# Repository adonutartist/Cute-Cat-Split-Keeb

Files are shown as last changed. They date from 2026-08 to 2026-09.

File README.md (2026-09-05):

# nemoPAD V1

A wireless split mechanical keyboard with per key kalih hotswap sockets, per key underglow RGB, a slide potentiometer for brightness control on the right half, and a rotary encoder for volume control on the left half. Uses a sandwich mount case (bottom case + plate + top frame) held together with heatset inserts and m2 20mm screws. The CAD features a unique design so it can join up to change into a full keeb visually. A project by Nemo made for Forge YSWS by Hackclub.

NOTE TO REVIEWER: I didn't make an assembly with case PCB and all components because Importing PCB into onshape was way too laggy and crashed, Adding lots of components also made onshape lag like crazy and crash so I abandoned doing that I hope you understand. I have a potato laptop from 2020 its really a budget laptop so please understand... 

## Useful links
- **Total time spent:** [56h 2m](https://hackatime.hackclub.com/@Nemo_Donut/project/Keeb)
- **Devlogs:** [`JOURNAL.md`](./JOURNAL.md)
- **Onshape:** [CAD part of the project](https://cad.onshape.com/documents/d864244cbdf9531af3bfa9a7/w/1dab6020ee26630806b280f9/e/8f26d1999df9f3097243071e)

## Features
- Wireless split halves, each with its own XIAO nRF52840 MCU and LiPo battery
- Full hotswap (Kailh CPG151101S11 sockets), no soldering required for switches
- Per key RGB backlight using reverse mount underglow (SK6812MINI-E)
- MCP23017 I2C GPIO expander per half for full matrix coverage
- Slide potentiometer (right half) for brightness
- Rotary encoder with push (left half) for volume
- Sandwich mount case: top frame + plate + bottom case, screwed together with heatset inserts and m2 20mm screws

## Images
- Full 3D model render of the assembled keyboard (both halves)
  

- PCB render/photo with components populated (both halves)
  

- Schematic screenshots (1st image is left and 2nd image is right)
  

- Exploded view of the sandwich mount stack (bottom case / plate / top frame)
  

- Decal logo, custom encoder knob and hackclub logo emboss
  

## From concept to CAD
<p align="center">
  1dd2464e-4f92-4cd7-a45b-adbc3583a7b4
  &nbsp;&nbsp;&nbsp;&nbsp;➡️&nbsp;&nbsp;&nbsp;&nbsp;
  
</p>

## Hardware design

### Sandwich mount stackup
| Layer | Thickness | Notes |
|---|---|---|
| Top frame | 6.3mm | Blind hole Ø3.5mm, 4.6mm deep for the heatset insert, no hole visible from outside |
| Plate | 1.5mm | Through hole Ø2.4mm for screw clearance |
| PCB | 1.6mm | |
| Bottom case (inner wall height) | 8mm | Clears the 3.05mm tall hotswap socket + ~3.16mm USB-C connector on the back layer with margin |
| Bottom case (bottom wall) | 3mm | Ø2.4mm x 1.2mm countersink on the underside so the screw head sits flush |

**Case is attached using** M2 x 4mm x 3.8mm OD brass heatset insert, M2 x 20mm countersunk screw.

**Battery pocket:** a local recessed pocket under the battery footprint on the inside of the bottom wall of bottom case (battery is the tallest bottom side component at ~5mm, taller than the general 6mm clearance zone needs). Battery wires are direct soldered to the BAT/GND test points, no connector.

## Bill of Materials
See [`BOM.csv`](./BOM.csv) for the full parts list with references, footprints, product links, and important notes.

### Summarised version:

| Component | Quantity | Total Price |
|---|---|---|
| 1N914 Diodes | 68 | ₹ 159.80 / $1.69 |
| SK6812MINI-E LEDs | 70 | ₹ 619.20 / $6.56 |
| 8.2k Resistor | 2 | ₹ 10.26 / $0.11 |
| 10k Resistor | 2 | ₹ 10.08 / $0.11 |
| Bourns Slide Potentiometer | 1 | ₹ 286.78 / $3.04 |
| Alps EC11E Rotary Encoder | 1 | NA (reused from kit) |
| Kailh Hotswap Sockets (all sizes) | 68 | ₹ 350.00 / $3.71 |
| MX-style Switches (all sizes) | 68 | ₹ 2,598.00 / $27.51 |
| Keycaps – 1u | 60 | ₹ 1,020.00 / $10.80 |
| Keycaps – 1.75u | 4 | ₹ 180.00 / $1.91 |
| Keycaps – 1.5u | 2 | ₹ 180.00 / $1.91 |
| Keycaps – 1.25u | 2 | NA (3D printed) |
| MCP23017 GPIO Expander | 2 | ₹ 539.00 / $5.71 |
| XIAO nRF52840 (modified) | 2 | ₹ 2,418.00 / $25.60 |
| LiPo Battery 500mAh | 2 | ₹ 476.98 / $5.05 |
| PCB (2-layer panel) | 5 | ₹ 5,003.00 / $52.97 |
| Heatset Insert | 8 | ₹ 108.65 / $1.15 |
| Case Screw | 8 | (included above) |
| 3D Printed Parts (case, plate, frame, knob, keycap) | 7 | ₹ 1,956.06 / $20.71 |
| **GRAND TOTAL** | | **₹ 15,915.81 / $168.51** |

## Assembly
1. Solder components to both PCB halves (or have them assembled), separate the panel at the mousebite tabs
2. Solder battery leads to BAT/GND test points on each half
3. Insert hotswap sockets, install switches
4. Heatset the M2 inserts into each top frame's blind holes
5. Sandwich bottom case -> PCB -> plate -> top frame, secure with M2x18mm screws
6. Flahing steps still needs work.

## Flashing

The keyboard uses two Seeed XIAO nRF52840 boards, one for each half. Separate firmware files are provided for the left and right halves.

### Requirements

* USB-C data cable
* Computer
* The appropriate `.uf2` firmware file

### Flash the Left Half

1. Connect the **left-half XIAO nRF52840** to your computer via USB.
2. Double-click the XIAO's **Reset** button to enter bootloader mode.
3. A USB mass-storage drive should appear.
4. Copy `zmk_left.uf2` onto the bootloader drive (Found inside Firmware folder).
5. The XIAO will automatically reboot after the firmware is copied.

### Flash the Right Half

1. Connect the **right-half XIAO nRF52840** to your computer via USB.
2. Double-click the XIAO's **Reset** button to enter bootloader mode.
3. A USB mass-storage drive should appear.
4. Copy `zmk_right.uf2` onto the bootloader drive (Found inside Firmware folder).
5. The XIAO will automatically reboot after the firmware is copied.

### Firmware Source

The firmware is built using **ZMK** with the Seeed XIAO nRF52840 target.

The provided firmware files are:

```text
Firmware/
├── zmk_left.uf2
└── zmk_right.uf2
```

The firmware currently represents the development stage prototype. Both left and right firmware builds complete successfully; physical flashing and keyboard testing will be performed once the PCBs and components are available.

---

<p align="center">
  nemo
</p>

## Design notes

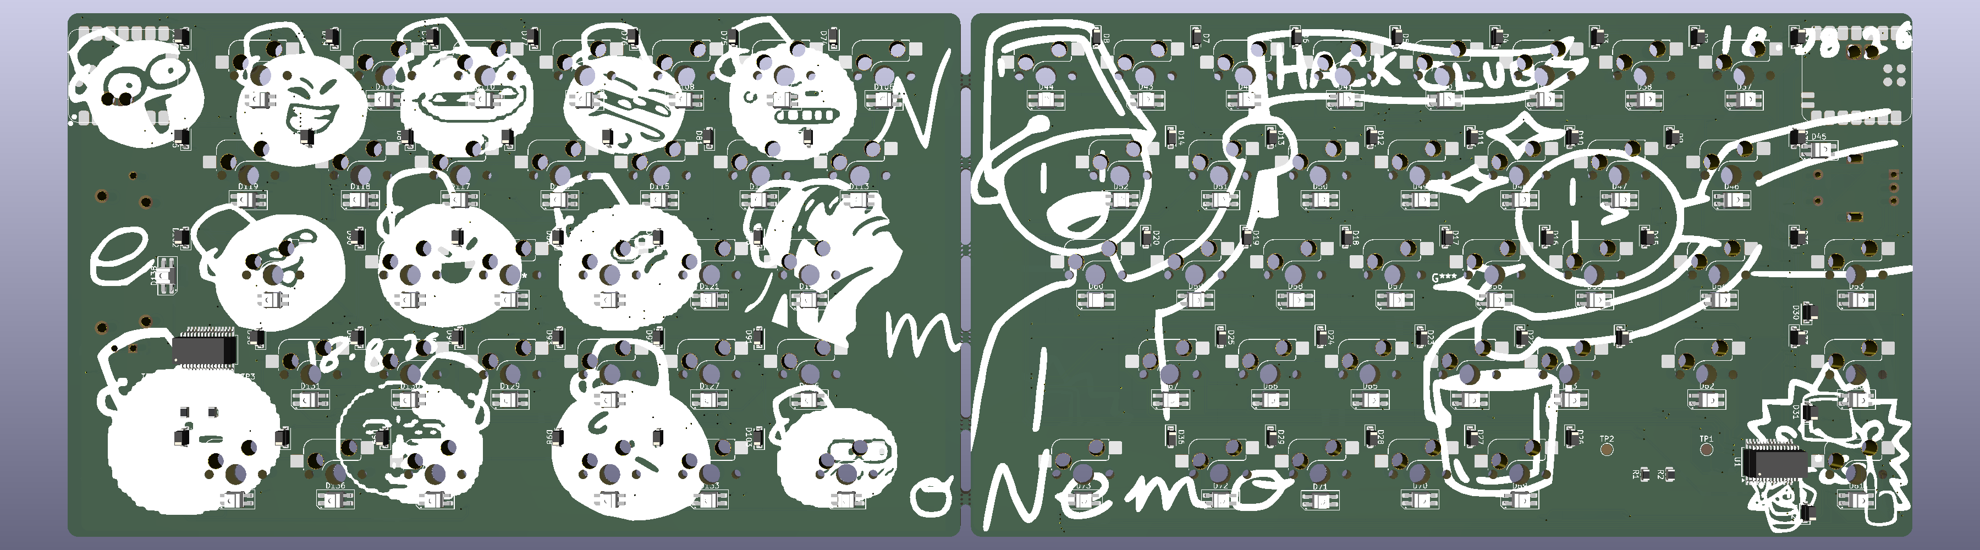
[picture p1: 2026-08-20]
kicad/kicadback.png

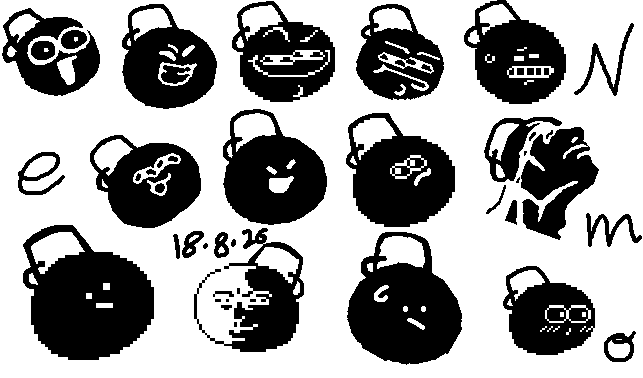
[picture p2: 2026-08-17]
kicad/silkscreen right front.png

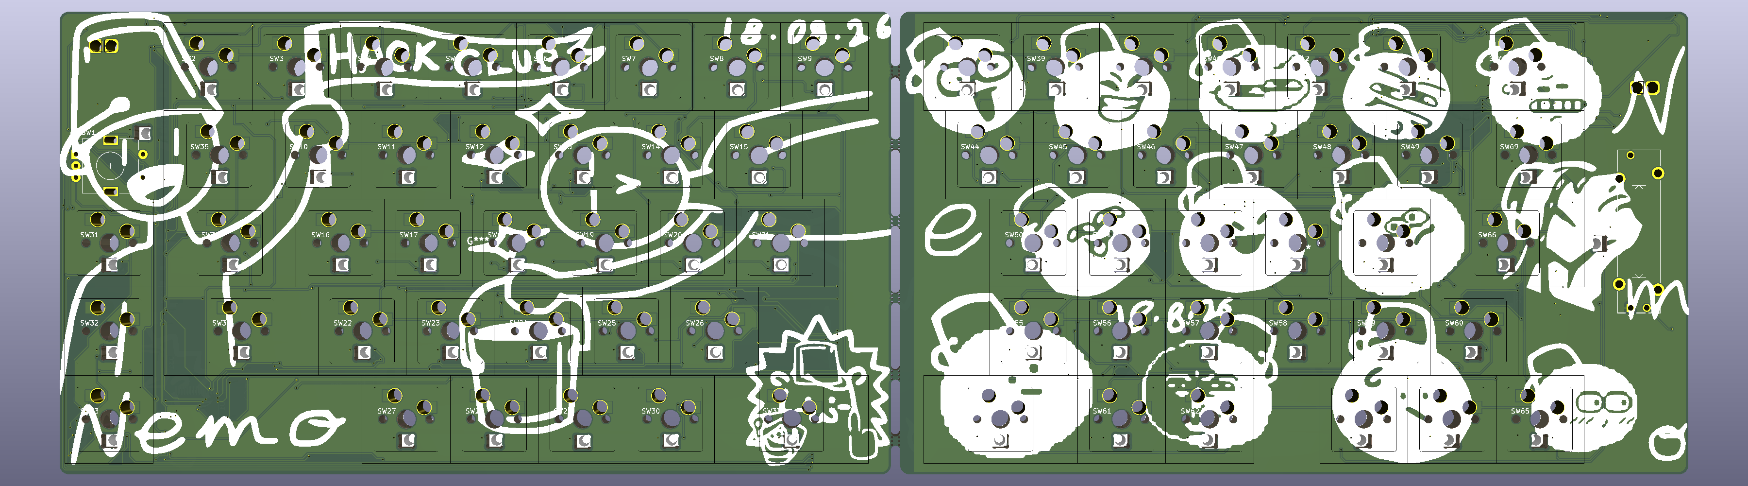
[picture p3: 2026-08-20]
kicad/kicad.png

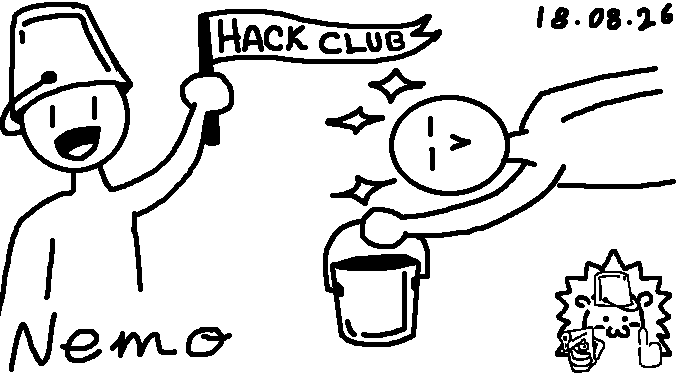
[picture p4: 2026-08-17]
kicad/silkscreen left front.png

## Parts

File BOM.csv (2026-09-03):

Category | Reference(s) | Qty | Part / Value | Footprint / Package | Description | Unit Price | Total | Notes
Electronics | D1-D32 (left), D66-D101 (right) | 68 | 1N914 | SOD-123 | Small signal switching diode (per-key) | ₹ 2.35 / $0.02 | ₹ 159.80 / $1.69 | https://robu.in/product/1n4148w-7-f-diodes-incorporated-100v-independent-type-1-25v150ma-4ns-300ma-sod-123-switching-diodes-rohs/
Electronics | D33-D65 (left), D102-D138 (right) | 70 | SK6812MINI-E | LED_SK6812MINI-E_3.2x2.8mm ReverseMount | Per-key + underglow RGB LED (reverse mount = bottom side) | ₹ 8.60 / $0.09 | ₹ 619.20 / $6.56 | https://www.etstore.in/products/e9974?variant=48993209319675 ; gonna order 72 because it comes in pack of 3
Electronics | R1, R3 | 2 | 8.2k | 8.2k | Battery voltage-divider resistor (top) | ₹ 0.38 / $0.00 | ₹ 10.26 / $0.11 | https://robu.in/product/wr08x8201ftl-walsin-125mw-thick-film-resistors-150v-%c2%b1100ppm-%e2%84%83-%c2%b11-8-2k%cf%89-0805-chip-resistor-surface-mount-rohs/ ; buying 27 to meet minimum order value
Electronics | R2, R4 | 2 | 10k | 10k | Battery voltage-divider resistor (bottom) | ₹ 0.72 / $0.01 | ₹ 10.08 / $0.11 | https://robu.in/product/ac0805fr-0710kl-yageo-res-thick-film-0805-10k-ohm-1-0-125w1-8w-%c2%b1100ppm-c-pad-smd-t-r-automotive-aec-q200/ ; buying 14 to meet minimum order value
Electronics | RV1 | 1 | Bourns PTA2043-2015DPB103 | Potentiometer_Bourns_PTA2043_Single_Slide | Slide potentiometer, 20mm travel, brightness/volume control (left half only) | ₹ 211.78 / $2.24 | ₹ 286.78 / $3.04 | https://www.tanotis.com/products/bourns-pta2043-2015cpb103-pot-slide-10kohm-0-1w?gad_source=1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
Electronics | SW33 | 1 | Alps EC11E | RotaryEncoder_Alps_EC11E-Switch_Vertical_H20mm | Rotary encoder w/ push switch, 20mm vertical shaft (right half only) | NA | NA | got one extra in my hackpad kit so gonna use that
Electronics | SW1-28, SW34-65 | 60 | SW_Push (1u) | PCM_marbastlib-mx CPG151101S11 1u | Kailh hotswap socket - 1u keys | ₹ 5 / $0.05 | ₹ 350 / $3.71 | https://neomacro.in/products/jerrzi-mx-hotswap-sockets?variant=51634860622102 ; i am buying 70 because its a pack of 10
Electronics | SW29-30, SW66, SW69 | 4 | SW_Push (1.75u) | PCM_marbastlib-mx CPG151101S11 1.75u | Kailh hotswap socket - 1.75u keys | same | total above | same
Electronics | SW31, SW68 | 2 | SW_Push (1.5u) | PCM_marbastlib-mx CPG151101S11 1.5u | Kailh hotswap socket - 1.5u keys | same | total above | same
Electronics | SW32, SW67 | 2 | SW_Push (1.25u) | PCM_marbastlib-mx CPG151101S11 1.25u | Kailh hotswap socket - 1.25u keys | same | total above | same
Electronics | SW1-28, SW34-65 | 60 | SW_Push (1u) | PCM_marbastlib-mx CPG151101S11 1u | MX-style switch - 1u keys | ₹ 28.88 / $0.31 | ₹ 2,598.00 / $27.51 | https://stackskb.com/store/akko-creamy-cyan-switch-pack-of-45-pre-order/ ; pack of 45 so gotta buy 2
Electronics | SW29-30, SW66, SW69 | 4 | SW_Push (1.75u) | PCM_marbastlib-mx CPG151101S11 1.75u | MX-style switch - 1.75u keys | same | total above | same
Electronics | SW31, SW68 | 2 | SW_Push (1.5u) | PCM_marbastlib-mx CPG151101S11 1.5u | MX-style switch - 1.5u keys | same | total above | same
Electronics | SW32, SW67 | 2 | SW_Push (1.25u) | PCM_marbastlib-mx CPG151101S11 1.25u | MX-style switch - 1.25u keys | same | total above | same
Electronics | SW1-28, SW34-65 | 60 | SW_Push (1u) | PCM_marbastlib-mx CPG151101S11 1u | MX-style keycap - 1u keys | ₹ 17 / $0.18 | ₹ 1020 / $10.80 | https://neomacro.in/products/dsa-blank-keycaps?variant=51613911908630 , https://neomacro.in/products/dsa-blank-keycaps?variant=51613911744790 ; pack of 10
Electronics | SW29-30, SW66, SW69 | 4 | SW_Push (1.75u) | PCM_marbastlib-mx CPG151101S11 1.75u | MX-style keycap - 1.75u keys | ₹ 45 / $0.48 | ₹ 180 / $1.91 | https://neomacro.in/products/dsa-blank-keycaps?variant=51613911974166 , https://neomacro.in/products/dsa-blank-keycaps?variant=51613911810326 ; pack of 2
Electronics | SW31, SW68 | 2 | SW_Push (1.5u) | PCM_marbastlib-mx CPG151101S11 1.5u | MX-style keycap - 1.5u keys | ₹ 45 / $0.48 | ₹ 180 / $1.91 | https://neomacro.in/products/dsa-blank-keycaps?variant=51613911941398 , https://neomacro.in/products/dsa-blank-keycaps?variant=51613911777558 ; pack of 2
Electronics | SW32, SW67 | 2 | SW_Push (1.25u) | PCM_marbastlib-mx CPG151101S11 1.25u | MX-style keycap - 1.25u keys | NA | NA | will 3D print cuz that's the best cheap option
Electronics | U1, U3 | 2 | MCP23017 | SSOP-28 | 16-bit I2C GPIO expander | ₹178.48 / $1.89 | ₹539.00 / $5.71 | https://www.lioncircuits.com/parts/MCP23017T-E%2FSS
Electronics | U2, U4 | 2 | Modified XIAO nRF52840 SMD | modified-XIAO-nRF52840-SMD (custom) | MCU, back layer of PCB, standard USB-C connector (~3.16mm tall) | ₹ 1,209.00 / $12.80 | ₹ 2,418.00 / $25.60 | https://robu.in/product/seeed-studio-xiao-ble-nrf52840/
Power | Battery | 2 | LiPo 502535 500mAh | N/A | One battery per half, direct-soldered to BAT/GND test points, sits in local case-floor recess | ₹ 238.49 / $2.53 | ₹ 476.98 / $5.05 | https://thinkrobotics.com/products/bis-certified-3-7v-lipo-batteries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
Fabrication | PCB | 5 | 2-layer PCB panel (L+R mousebite-panelized) | N/A | Fabricated as single panel with mousebite tabs; snaps into left + right boards after fab | ₹ 1,000.60 / $10.59 | ₹5,003.00 / $52.97 | https://res.cloudinary.com/dtz0urit6/image/upload/q_auto:best,f_png/cloudinary-tools-uploads/m2ix18f4xx1hjhega9rd ; robu.in PCB manufacturing service cuz Seeed Fusion is way too costly
Mechanical | Heatset insert | 8 | M2 x 4mm x 3.8mm OD | Brass knurled heatset insert | Installed in top frame blind holes (6.2mm deep) | ₹ 2.00 / $0.02 | ₹ 108.65 / $1.15 | https://onlyscrews.in/products/m2-x-4mm-brass-threaded-inserts?variant=49423172829497
Mechanical | Case screw | 8 | M2 x 20mm countersunk | Steel or A2 stainless | Bottom case -> plate -> top frame insert | ₹ 2.20 / $0.02 | total above | https://onlyscrews.in/products/m2-x-20mm-phillips-csk-ss-304-screw-dia-2mm-length-20mm?variant=51155250610489
Mechanical | Bottom case | 2 | Custom 3D print | N/A | 3mm bottom wall + 6mm wall height + local battery-pocket boss | NA | $20.71 / ₹1,956.06 | From printing legion
Mechanical | Plate | 2 | Custom 3D print | 1.5mm | Switch mounting plate with screw clearance + pot/encoder cutouts | NA | total above | same
Mechanical | Top frame | 2 | Custom 3D print | 8mm | Holds heatset inserts, blind holes only (no visible top holes) | NA | total above | same
Mechanical | Encoder knob | 1 | Custom 3D print | NA | Goes on top of encoder knob to make it look cool | NA | total above | same
 |  |  |  |  |  | GRAND TOTAL | ₹ 15,915.81 / $168.51

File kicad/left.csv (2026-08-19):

Reference | Qty | Value | DNP | Exclude from BOM | Exclude from Board | Exclude from Simulation | Exclude from Position Files | Footprint | Datasheet | Description
D66,D67,D68,D69,D70,D71,D72,D73,D74,D75,D76,D77,D78,D79,D80,D81,D82,D83,D84,D85,D86,D87,D88,D89,D90,D91,D92,D93,D94,D95,D96,D97,D98,D99,D100,D101 | 36 | 1N914 |  |  |  |  | ${EXCLUDE_FROM_POS_FILES} | Diode_SMD:D_SOD-123 | http://www.vishay.com/docs/85622/1n914.pdf | 100V 0.3A Small Signal Fast Switching Diode, DO-35
D102,D103,D104,D105,D106,D107,D108,D109,D110,D111,D112,D113,D114,D115,D116,D117,D118,D119,D120,D121,D122,D123,D124,D125,D126,D127,D128,D129,D130,D131,D132,D133,D134,D135,D136,D137,D138 | 37 | SK6812MINI-E |  |  |  |  | ${EXCLUDE_FROM_POS_FILES} | LED_SMD:LED_SK6812MINI-E_3.2x2.8mm_P1.5mm_ReverseMount | https://www.lcsc.com/datasheet/C5149201.pdf | RGB LED with integrated controller
R3 | 1 | 806k |  |  |  |  | ${EXCLUDE_FROM_POS_FILES} | Resistor_SMD:R_0805_2012Metric |  | Resistor
R4 | 1 | 1M |  |  |  |  | ${EXCLUDE_FROM_POS_FILES} | Resistor_SMD:R_0805_2012Metric |  | Resistor
SW33 | 1 | RotaryEncoder_Switch |  |  |  |  | ${EXCLUDE_FROM_POS_FILES} | Rotary_Encoder:RotaryEncoder_Alps_EC11E-Switch_Vertical_H20mm |  | Rotary encoder, dual channel, incremental quadrate outputs, with switch
SW34,SW35,SW36,SW37,SW38,SW39,SW40,SW41,SW42,SW43,SW44,SW45,SW46,SW47,SW48,SW49,SW50,SW51,SW52,SW53,SW54,SW55,SW56,SW57,SW58,SW59,SW60,SW61,SW62,SW63,SW64,SW65 | 32 | SW_Push |  |  |  |  | ${EXCLUDE_FROM_POS_FILES} | PCM_marbastlib-mx:SW_MX_HS_CPG151101S11_1u |  | Push button switch, generic, two pins
SW66,SW69 | 2 | SW_Push |  |  |  |  | ${EXCLUDE_FROM_POS_FILES} | PCM_marbastlib-mx:SW_MX_HS_CPG151101S11_1.75u |  | Push button switch, generic, two pins
SW67 | 1 | SW_Push |  |  |  |  | ${EXCLUDE_FROM_POS_FILES} | PCM_marbastlib-mx:SW_MX_HS_CPG151101S11_1.25u |  | Push button switch, generic, two pins
SW68 | 1 | SW_Push |  |  |  |  | ${EXCLUDE_FROM_POS_FILES} | PCM_marbastlib-mx:SW_MX_HS_CPG151101S11_1.5u |  | Push button switch, generic, two pins
TP3 | 1 | BAT |  |  |  |  | ${EXCLUDE_FROM_POS_FILES} | TestPoint:TestPoint_Pad_D2.0mm |  | test point
TP4 | 1 | GND |  |  |  |  | ${EXCLUDE_FROM_POS_FILES} | TestPoint:TestPoint_Pad_D2.0mm |  | test point
U3 | 1 | MCP23017x-x-SS |  |  |  |  | ${EXCLUDE_FROM_POS_FILES} | Package_SO:SSOP-28_5.3x10.2mm_P0.65mm | https://ww1.microchip.com/downloads/aemDocuments/documents/APID/ProductDocuments/DataSheets/MCP23017-Data-Sheet-DS20001952.pdf | 16-bit I/O expander, I2C, interrupts, w pull-ups, SSOP-28
U4 | 1 | XIAO-nRF52840-SMD |  |  |  |  | ${EXCLUDE_FROM_POS_FILES} | modified-XIAO-nRF52840-SMD:modified-XIAO-nRF52840-SMD

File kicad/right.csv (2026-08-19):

Reference | Qty | Value | DNP | Exclude from BOM | Exclude from Board | Exclude from Simulation | Exclude from Position Files | Footprint | Datasheet
D1,D2,D3,D4,D5,D6,D7,D8,D9,D10,D11,D12,D13,D14,D15,D16,D17,D18,D19,D20,D21,D22,D23,D24,D25,D26,D27,D28,D29,D30,D31,D32 | 32 | 1N914 |  |  |  |  | ${EXCLUDE_FROM_POS_FILES} | Diode_SMD:D_SOD-123 | http://www.vishay.com/docs/85622/1n914.pdf
D33,D34,D35,D36,D37,D38,D39,D40,D41,D42,D43,D44,D45,D46,D47,D48,D49,D50,D51,D52,D53,D54,D55,D56,D57,D58,D59,D60,D61,D62,D63,D64,D65 | 33 | SK6812MINI-E |  |  |  |  | ${EXCLUDE_FROM_POS_FILES} | LED_SMD:LED_SK6812MINI-E_3.2x2.8mm_P1.5mm_ReverseMount | https://www.lcsc.com/datasheet/C5149201.pdf
R1 | 1 | 806k |  |  |  |  | ${EXCLUDE_FROM_POS_FILES} | Resistor_SMD:R_0805_2012Metric
R2 | 1 | 1M |  |  |  |  | ${EXCLUDE_FROM_POS_FILES} | Resistor_SMD:R_0805_2012Metric
RV1 | 1 | R_Potentiometer |  |  |  |  | ${EXCLUDE_FROM_POS_FILES} | Potentiometer_THT:Potentiometer_Bourns_PTA2043_Single_Slide
SW1,SW2,SW3,SW4,SW5,SW6,SW7,SW8,SW9,SW10,SW11,SW12,SW13,SW14,SW15,SW16,SW17,SW18,SW19,SW20,SW21,SW22,SW23,SW24,SW25,SW26,SW27,SW28 | 28 | SW_Push |  |  |  |  | ${EXCLUDE_FROM_POS_FILES} | PCM_marbastlib-mx:SW_MX_HS_CPG151101S11_1u
SW29,SW30 | 2 | SW_Push |  |  |  |  | ${EXCLUDE_FROM_POS_FILES} | PCM_marbastlib-mx:SW_MX_HS_CPG151101S11_1.75u
SW31 | 1 | SW_Push |  |  |  |  | ${EXCLUDE_FROM_POS_FILES} | PCM_marbastlib-mx:SW_MX_HS_CPG151101S11_1.5u
SW32 | 1 | SW_Push |  |  |  |  | ${EXCLUDE_FROM_POS_FILES} | PCM_marbastlib-mx:SW_MX_HS_CPG151101S11_1.25u
TP1 | 1 | BAT |  |  |  |  | ${EXCLUDE_FROM_POS_FILES} | TestPoint:TestPoint_Pad_D2.0mm
TP2 | 1 | GND |  |  |  |  | ${EXCLUDE_FROM_POS_FILES} | TestPoint:TestPoint_Pad_D2.0mm
U1 | 1 | MCP23017x-x-SS |  |  |  |  | ${EXCLUDE_FROM_POS_FILES} | Package_SO:SSOP-28_5.3x10.2mm_P0.65mm | https://ww1.microchip.com/downloads/aemDocuments/documents/APID/ProductDocuments/DataSheets/MCP23017-Data-Sheet-DS20001952.pdf
U2 | 1 | XIAO-nRF52840-SMD |  |  |  |  | ${EXCLUDE_FROM_POS_FILES} | modified-XIAO-nRF52840-SMD:modified-XIAO-nRF52840-SMD

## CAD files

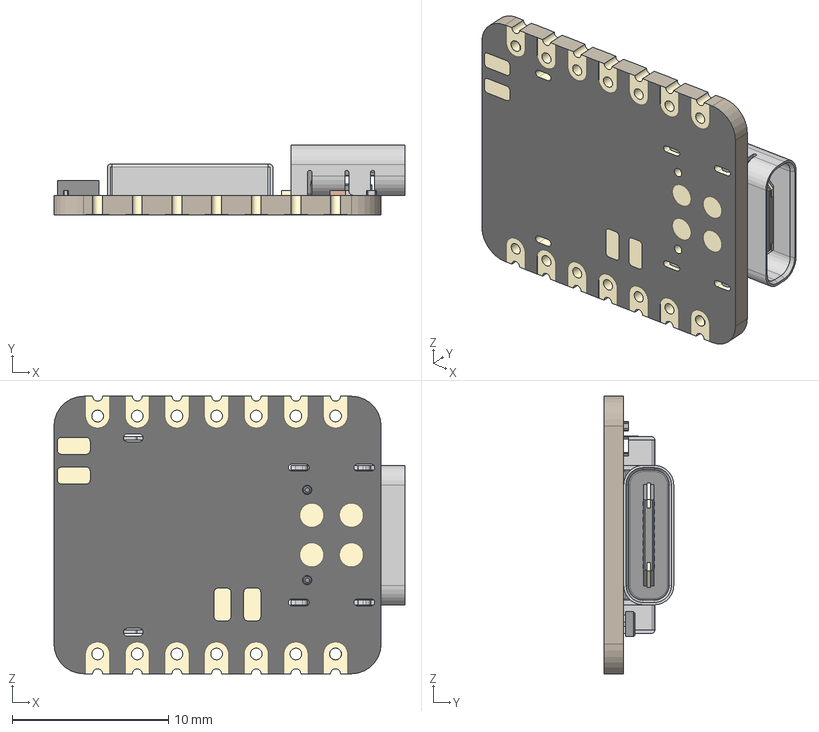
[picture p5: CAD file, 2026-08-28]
kicad/XIAO-nRF52840 v15.step
22.5 x 4.46 x 17.8 mm
BOSS-EXTRUDE14_8_
BOSS-EXTRUDE7_4_
BOSS-EXTRUDE7_3_
BOSS-EXTRUDE14_4_
BOSS-EXTRUDE14_2_
BOSS-EXTRUDE14_11_
BOSS-EXTRUDE7_7_
BOSS-EXTRUDE14_9_
BOSS-EXTRUDE14_3_
BOSS-EXTRUDE14_7_
MIRROR2
BOSS-EXTRUDE14_5_
BOSS-EXTRUDE14_12_
BOSS-EXTRUDE7_8_
BOSS-EXTRUDE7_1_
BOSS-EXTRUDE14_10_
BOSS-EXTRUDE7_9_
BOSS-EXTRUDE14_6_
BOSS-EXTRUDE14_1_
BOSS-EXTRUDE7_6_
BOSS-EXTRUDE7_2_
CUT-EXTRUDE5
BOSS-EXTRUDE7_5_
Shield
Pins
CAP x 2
ANT1
Silkscreen
CAP 3
LED
USR
2 v1

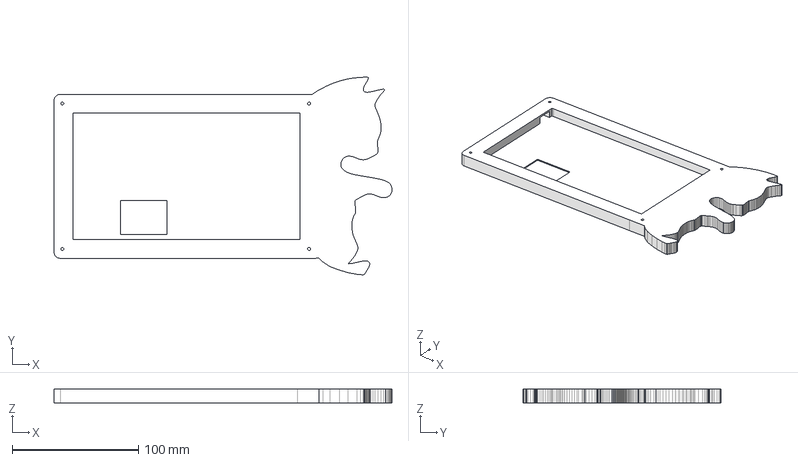
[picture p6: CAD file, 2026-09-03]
Production/3D Print Files/Bottom case/Left/left bottom case.step
267.9 x 156.7 x 11.0 mm

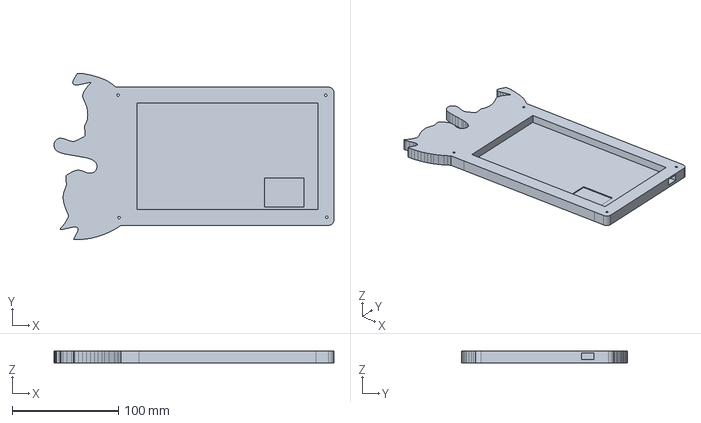
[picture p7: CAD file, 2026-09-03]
Production/3D Print Files/Bottom case/Right/right bottom case.step
263.6 x 156.7 x 11.0 mm

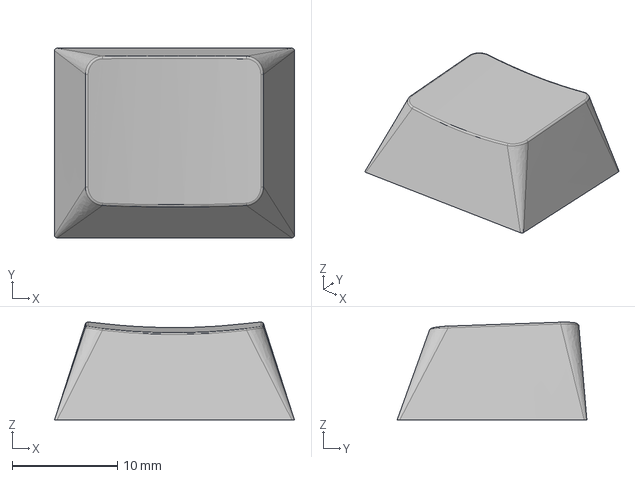
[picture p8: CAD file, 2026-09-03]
Production/3D Print Files/Misc/1.25u keycap black.step
22.8 x 18.0 x 9.28 mm

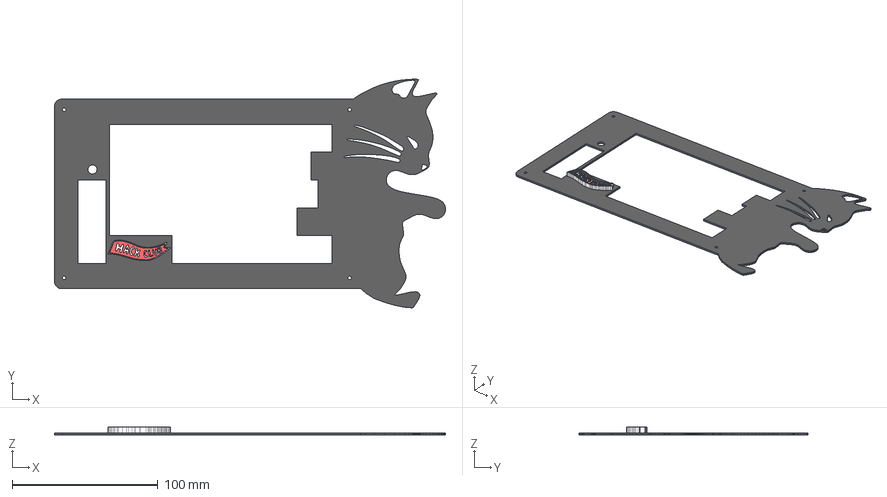
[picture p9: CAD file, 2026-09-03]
Production/3D Print Files/Plate/Left/left plate.step
267.9 x 156.7 x 5.50 mm

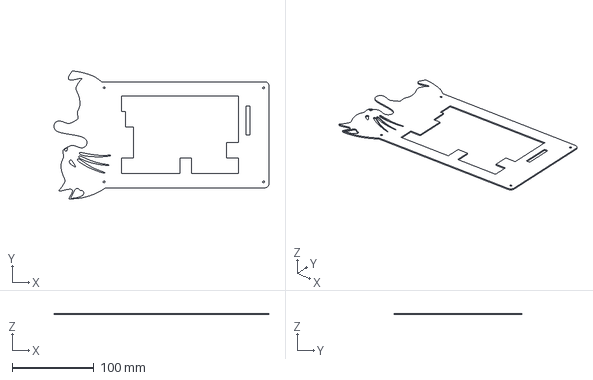
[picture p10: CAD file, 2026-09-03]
Production/3D Print Files/Plate/Right/right plate.step
263.6 x 156.7 x 1.50 mm

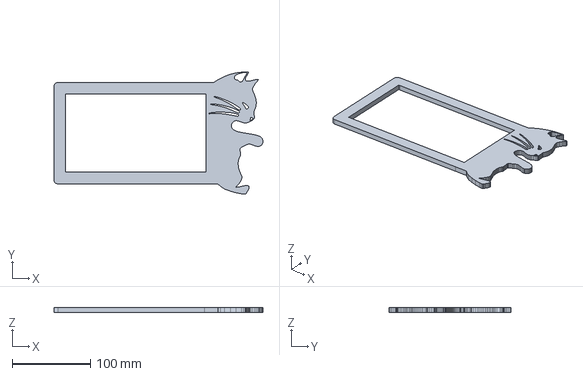
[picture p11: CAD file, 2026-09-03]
Production/3D Print Files/Top frame/Left/left top frame.step
267.9 x 156.7 x 6.30 mm

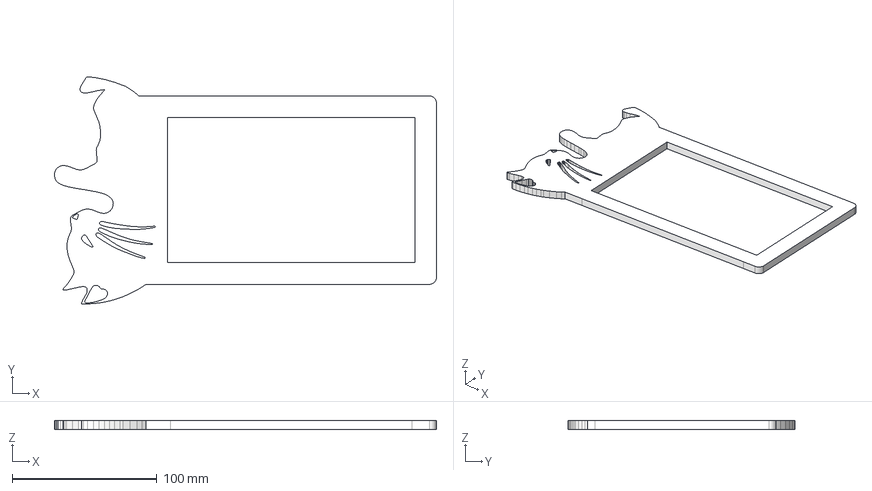
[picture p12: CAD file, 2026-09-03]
Production/3D Print Files/Top frame/Right/right top frame.step
263.6 x 156.7 x 6.30 mm

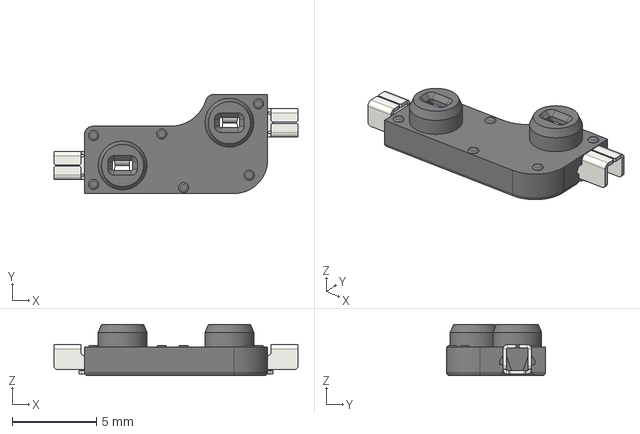
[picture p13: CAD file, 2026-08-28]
kicad/HS_CPG151101S11_MX.step
14.5 x 5.89 x 3.05 mm
Contact x 2

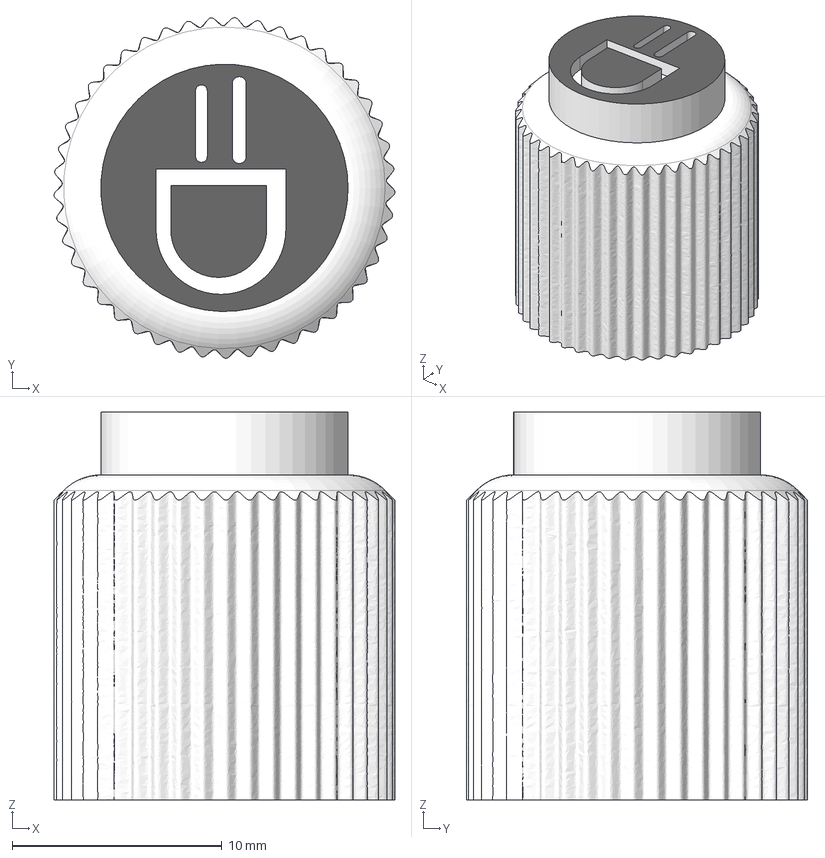
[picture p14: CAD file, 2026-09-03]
Production/3D Print Files/Misc/EC11 Encoder Knob D Shaft - brep_1.step
16.3 x 16.2 x 18.5 mm

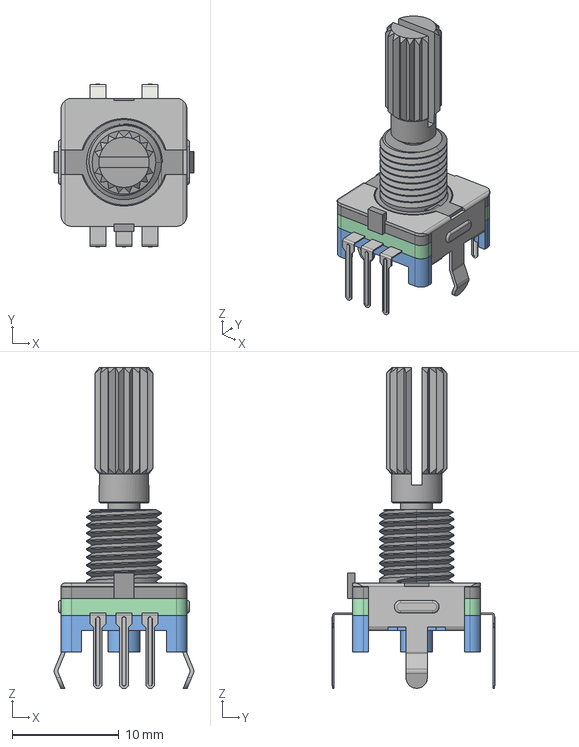
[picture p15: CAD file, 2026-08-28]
kicad/EC11_Rotary_Encoder_Switched.step
13.1 x 15.3 x 30.1 mm

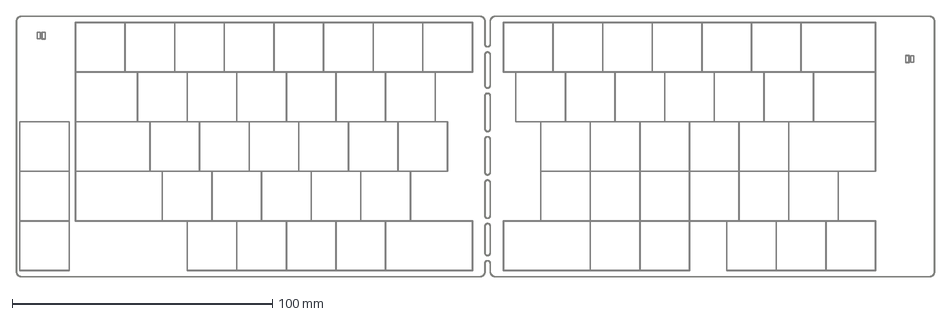
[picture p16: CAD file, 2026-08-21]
kicad/kicad.dxf
352.6 x 100.1 mm

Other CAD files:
Production/3D Print Files/Misc/1.25u keycaps grey.step
Production/3D Print Files/Misc/1.25u keycaps black.stl
Production/3D Print Files/Bottom case/Left/left bottom case.stl
Production/3D Print Files/Bottom case/Right/right bottom case.stl
Production/3D Print Files/Misc/1.25u keycaps grey.stl
Production/3D Print Files/Misc/EC11 Encoder Knob D Shaft - brep_1.stl
Production/3D Print Files/Plate/Left/left plate.stl
Production/3D Print Files/Plate/Right/right plate.stl
Production/3D Print Files/Top frame/Left/left top frame.stl
Production/3D Print Files/Top frame/Right/right top frame.stl

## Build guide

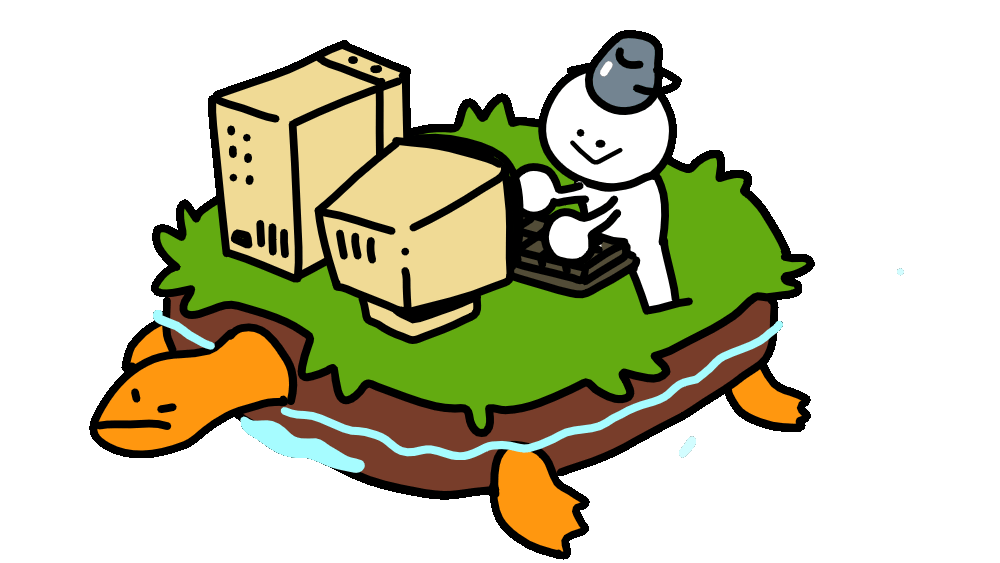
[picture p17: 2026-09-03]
Production/3D Print Files/Plate/Right/Decal.png

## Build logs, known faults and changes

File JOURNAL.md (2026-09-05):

# DEVLOG #1

* **Date:** 16 July 2026, From 2am to 3am

* **Overview:**
Made concept art for my keeb in ms paint. Majority of time spent deciding the layout and researching about different components. 
Tomorrow will start working on the Schematic in Kicad.

* **[Lapse Recording](https://lapse.hackclub.com/timelapse/uUoo5ue_uYmt)**

* **Images:**
  > keeb concept

* **Total time spent:** 1 hour 10 minutes 

# DEVLOG #2

* **Date:** 16 July 10 PM to 17 July 3 AM 2026

* **Overview:**
Completed left half of the schematic

* **[Lapse Recording](https://lapse.hackclub.com/timelapse/0nxsD578l6Ia)**

* **Images:**
  > Screenshot (170)

* **Total time spent:** 2 hours 30 minutes 

# DEVLOG #3

* **Date:** 17 July 10 PM to 18 July 3 AM 2026

* **Overview:**
Completed right half of the schematic too and also did assigning footprints to my schematic components.

* **[Lapse Recording](https://lapse.hackclub.com/timelapse/P2gVyMNg1cGr)**

* **Images:**
  > Screenshot (173)

* **Total time spent:** 3 hours 1 minute

# DEVLOG #4

* **Date:** 19 July 10 PM to 20 July 3 AM 2026

* **Overview:**
Completed arranging the PCB and making the edge cut with mouse bites now gonna work on routing tomorrow ;-; still can't figure out how to add underglow effect :<

* **[Lapse Recording](https://lapse.hackclub.com/timelapse/Vg1iJTcSfPfV)**

* **Images:**
  > Screenshot (174)

* **Total time spent:** 3 hours 41 minutes

# DEVLOG #5

* **Date:** 15 August 10 PM to 15 August 2:20 AM 2026

* **Overview:**
Routing left side of PCB truly taking a toll on my life force ;-; frikin got softlocked at various points needed to redo some routes a couple times to get it right still stuck with some ;-; gng I js wanna sleep :< also I don't know why some parts are not being filled with GND filled zone ;-; its really eating up my brain cells trying to figure this out ;-;

* **[Lapse Recording](https://lapse.hackclub.com/timelapse/IlSIfrzwNU0s)**

* **Images:**
  > 

* **Total time spent:** 3 hours 44 minutes

# DEVLOG #6

* **Date:** 16 August 10 PM to 17 August 2:52 AM 2026

* **Overview:**
Finished routing left side of PCB and also successfully made a GND and +3.3v filled region on the two layers without leaving gaps. Had to rerout like 3 times to get this right ;-; anyways right side of PCB going pretty smoothly I think the suffering I endured while doing the left is now bearing fruit :3 it feels pretty easy routing now but still won't lie I hate routing!!!

* **[Lapse Recording](https://lapse.hackclub.com/timelapse/GN2Y_pQOUh5k)**

* **Images:**
  > 

* **Total time spent:** 2 hours 57 minutes

# DEVLOG #7

* **Date:** 17 August 10:50 PM to 18 August 2:54 AM 2026

* **Overview:**
Finished routing the right half of PCB and made art for silkscreen for both halves and added that too... asked some people to check if my PCB routing is correct so gonna wait on their reply ;-; found weird DRC errors which prolly meant nothing cuz it kept pointing at overlap boundary but my LEDs are designed for underglow so I dont know I shouldn't place em enside keycap boundary well anyways gotta get these errors clarified with someone with bigger brain than mine xDDD

* **[Lapse Recording](https://lapse.hackclub.com/timelapse/J2zB9yHQb8pH)**

* **Images:**
  > 

* **Total time spent:** 3 hours 29 minutes

# DEVLOG #8

* **Date:** 18 August 10:30 PM to 19 August 2:57 AM 2026

* **Overview:**
Couldn't get anything done! I recently moved to linux and i am only familiar with fusion360 i thought onshape would be easy but it requires such good internet connection ;-; this is so frikin cooked then I tried using freecad it's ui holy i couldn't find the option to extrude ;-; at this point I just have skill issues man.

* **[Lapse Recording](https://lapse.hackclub.com/timelapse/MF380lOOOztu)**

* **Images:**
  > nemo No images to show so here you go Mr. hedgehog Nemo

* **Total time spent:** 14 minutes 

# DEVLOG #9

* **Date:** 19 August 11:00 PM to 20 August 1:10 AM 2026

* **Overview:**
I kinda avoided doing CAD today cuz of this consistent headache I had all day but well I fixed some errors with footprints. I had posted my PCB on #electronics channel and someone replied back! He told me about how my hotswap key placement was wrong apparently hotswap pads require to be mounted on b.cu but mine was on f.cu so yeh I js had edit it all nothing much. Also some guy told me that if i have silkscreen art on pads it interferes with soldering don't rly get his point but i guess will have to revise silkscreen art ;-; Also good news I randomly found out I can export my custom layout as dxf!! Insane right? Its all so easy now I guess will have to use onshape

* **[Lapse Recording](https://lapse.hackclub.com/timelapse/CPJDpnVxVtwW)**

* **Images:**
  > srvimg

* **Total time spent:** 23 minutes 

# DEVLOG #10

* **Date:** 20 August 10:30 PM to 21 August 00:28 AM 2026

* **Overview:**
Still avoiding doing CAD. Someone told me to round corners of pcb to look cool so I did that. Also took couple images as good renders of PCB to put on readme llater. Nothing too fancy just some kindling etc...

* **[Lapse Recording](https://lapse.hackclub.com/timelapse/s1fZ1YkS1jc-)**

* **Images:**
  > kicadbackkicadsrvimg (1)

* **Total time spent:** 37 minutes 

# DEVLOG #11

* **Date:** 21 August 11 PM to 22 August 1:30 AM 2026

* **Overview:**
Finally started CAD!! Onshape is actually really similar to fusion I guess it was just me being stubborn ;-; also found out onshpae rendering part like the place where u go for doing photo session of ur CAD is paywalled ;-; really heartbreaking will have to find some alternative to that otherwise everything else is fine :3 kBai!

* **[Lapse Recording](https://lapse.hackclub.com/timelapse/Y-vAZevbnHuz)**

* **Images:**
  > 

* **Total time spent:** 2 hours 2 minutes

# DEVLOG #12

* **Date:** 23 August 10 PM to 23 August 11:53 PM 2026

* **Overview:**
CAD work decided mounting style and mouting hole size also started working on the cat design in figma pretty hard ngl i HATE FIGMA

* **[Lapse Recording](https://lapse.hackclub.com/timelapse/mRBZU7DT-jdH)**

* **Images:**
  > 

* **Total time spent:** 1 hour 46 minutes

# DEVLOG #13

* **Date:** 24 August Midnight to 24 August 2:59 AM 2026

* **Overview:**
After like 3 hours of just trying to do stuff I needed to delete my progress all because frikin FIGMAAA is frikin pissing me off I genuinely hate this piece of scrap man. I tried to get my cat design for like transforming into full keeb but unfortunately it turned out rly bad it got like some double borders which broke it int various parts and made me lag like insane i mean onshape was lagging.. so now i gotta redo this same thing tmrw :3 so sweet thx FIGMA

* **[Lapse Recording](https://lapse.hackclub.com/timelapse/fl6AMQ08l5pY)**

* **Images:**
  > 

* **Total time spent:** 1 hour 58 minutes

# DEVLOG #14

* **Date:** 25 August 00:40 to 25 August 3:00 AM 2026

* **Overview:**
Finally got the cat imported correctly frikin problem with svg dxf converts is gonna kill me man ;-; they always convert badly. also this time since starting from scratch i made sure to do both halves simultaneously :3

* **[Lapse Recording](https://lapse.hackclub.com/timelapse/Ib2qoODKg3mB)**

* **Images:**
  > 

* **Total time spent:** 2 hours 10 minutes

# DEVLOG #15

* **Date:** 26 August 00:40 to 26 August 2:45 AM 2026

* **Overview:**
Goddam man i HATE FIGMA it frikin makes ur lines so much thicker such that once i convert it to DXF its all multiple lines frikin pissed me off but finally with hardwork i did it!!!! and then my man Shadow (a fellow hackclubber) helped me a lot actually he helped a ton i was so dam confused with mounting style and heatset inserts and screws he frikin gave me enlightment clearing all my confusion xDDD love u man u are a goddam life saviour. so yeh now ik wht to do next its top frame and bottom also deciding on screws and heatset insert length etc. 

* **[Lapse Recording](https://lapse.hackclub.com/timelapse/8vGjv3wEbLbX)**

* **Images:**
  > 

* **Total time spent:** 2 hours 11 minutes

# DEVLOG #16

* **Date:** 26 August 11 PM to 27 August 2:49 AM 2026

* **Overview:**
Made top frame and the bottom case also add a dip for battery and made screw holes. Onshape is so annoying at times mannn I miss fusion360 it was way easier ;-; anyways tomorrow imma try to complete ths and ship my keeb for review so prolly my second last devlog :> 

* **[Lapse Recording](https://lapse.hackclub.com/timelapse/kax4btwylfyq)**

* **Images:**
  > 

* **Total time spent:** 3 hours 47 minutes

# DEVLOG #17

* **Date:** 27 August 10:30 PM to 28 August 2:58 AM 2026

* **Overview:**
Completed the CAD now need to make the assembly. would've shipped today but onshape wasted so much time crashing cuz i was tryna import my pcb step file from kicad ;-; now theres no way add pcb cuz onshape is js too dam trashy so i thought to js add the componenets at the right place but guess wht it now stutters i frikin added some keys and started lagging like insane no crashes but lag is SO DAM ANNOYING i hate this ;-; gonna ask in erebor if they got any solutions or maybe if i can omit this part ;-;

* **[Lapse Recording](https://lapse.hackclub.com/timelapse/MEkGXJbaae5l)**

* **Images:**
  > 

* **Total time spent:** 4 hours 18 minutes

# DEVLOG #18

* **Date:** 29 August 00:13 AM to 29 August 2:55 AM 2026

* **Overview:**
Couldn't proceed with the assembly frikin lag killing me ;-; so I started doing the BOM and readme. Completed the readme almost doe with bom too so will ship like tmrw fs!!

* **No Lapse Recording for today cuz it was js me doomscrolling so many websites for parts and componenets ;-;**

* **Images:**
  > 

* **Total time spent:** 2 hours 42 minutes

# DEVLOG #19

* **Date:** 29 August 11 PM to 30 August 2:22 AM 2026

* **Overview:**
Completed the BOM! found out tht my case is too big for any 3d printer so i gotta split it ;-; yeh its sad wht could i possibly even do to fix this ;-; so yeh gotta wwork with this now and uhh not doing assembly cuz yeh onshape not build for tht and my lappy is ancient. Also looked at ZMK documentations i dont rly like reading documentations so imma js try looking at some examples tht others have made and then reverse engineer from there to make my own firmware for my keeb. also made a list of keybinds like which switch for wht etc... 

* **No Lapse Recording for today cuz it was js me staring at my screen doing boring work which is not technically that important will record mmyself doing firmware tho so stay tuned**

* **Images:**
  > 

* **Total time spent:** 3 hours 12 minutes

# DEVLOG #20

* **Date:** 2 September 10 PM to 3 September 1 AM and 3 September 11 PM to 4 September 2:40 AM 2026

* **Overview:**
Completed the BOM againnnn... yeh so this one guy named neeraj on slack he helped me a lot with this so wht happened was that my BOM total amount looked hilarious so i had to find ways to reduce this but i js couldn't and then this neeraj guy gave me a slink to a slack channel canvas that had listings for all cheap trusted websites for keyboard parts and tht greatly reduced my total amount from 300 usd to 170 usd!! yeh i am not kidding this was frikin life changer. Also i had to make some minor changes in CAD cuz i js couldn't find m2 18mm screws so i went with m2 20mm so increases the height of bottom case and then the inserts i used has OD 3.5mm but in the websites i could only find OD 3.8mm so i js changes hole size according to tht! now everything is cool BOM is finally complete. I also made two 1.25u keycaps for 3D printing cuz my keycap set didnt had those and then i also made a knob for rotary encoder and added hackclub logo emboss and a decal for my logog.

* **No Lapse Recording**

* **Images:**
  > 

* **Total time spent:** 6 hours 40 minutes

# DEVLOG #21

* **Date:** 5 September 10 PM to 6 September 2:35 AM 2026

* **Overview:**
Completed the firmware first I quickly read the zmk docs understood actually i also read it once during the day it was pretty easy so i completed all of it in one sitting... dont know if it will work but its barebones enough to ship...
last devlog of design phase prolly will ship and hope to get aprroved now lol.

* **[Lapse Recording](https://lapse.hackclub.com/timelapse/QY5ti9HtTKar)**

* **Images:**
  > 

* **Total time spent:** 3 hours 41 minutes

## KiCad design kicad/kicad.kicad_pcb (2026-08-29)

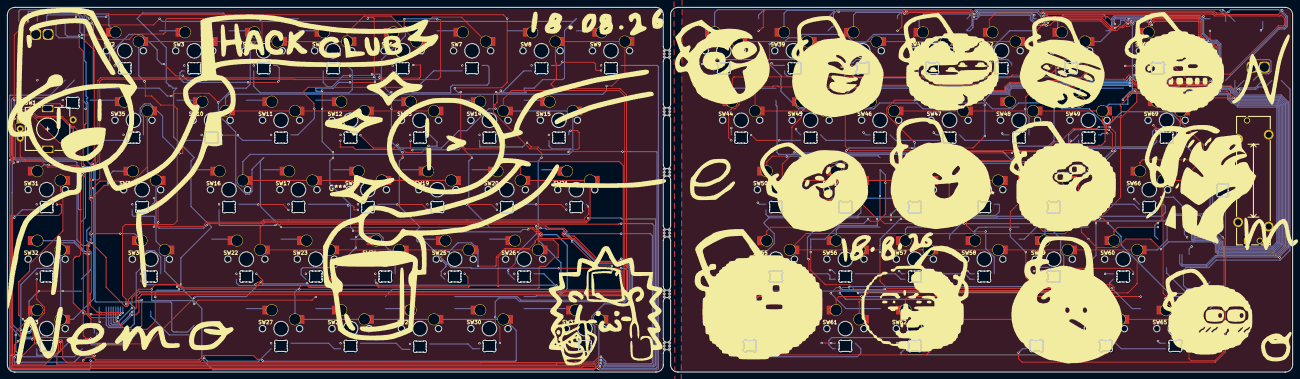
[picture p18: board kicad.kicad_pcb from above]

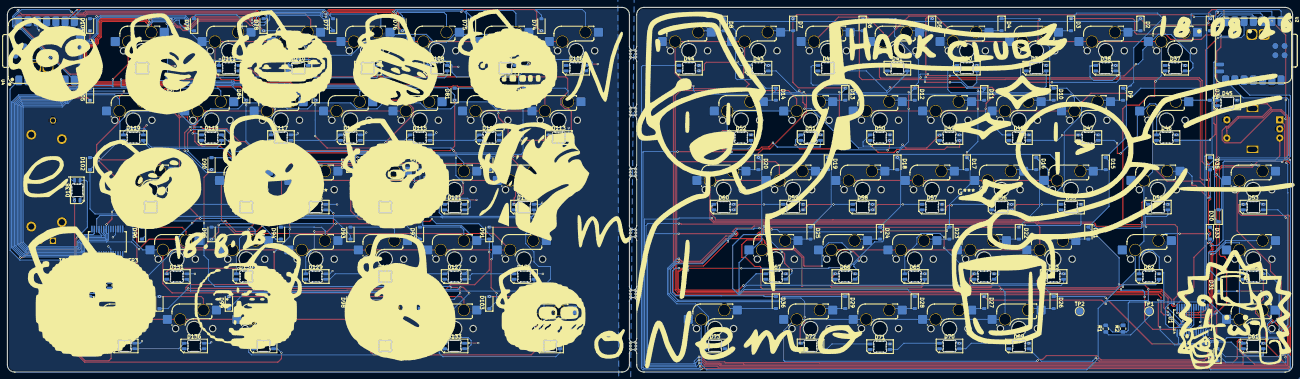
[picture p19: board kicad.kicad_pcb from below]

Board: 2 copper layers, 352.5 x 100.0 mm, 220 parts (150 on the bottom side), 174 nets.

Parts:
D1, D2, D3, D4, D5, D6, D7, D8, D9, D10, D11, D12, D13, D14, D15, D16, D17, D18, D19, D20, D21, D22, D23, D24, D25, D26, D27, D28, D29, D30, D31, D32, D33, D34, D35, D36, D74, D75, D76, D77, D78, D79, D80, D81, D82, D83, D84, D85, D86, D87, D88, D89, D90, D91, D92, D93, D94, D95, D96, D97, D98, D99, D100, D101, D102, D103, D104, D105: 1N914; D_SOD-123
D37, D38, D39, D40, D41, D42, D43, D44, D45, D46, D47, D48, D49, D50, D51, D52, D53, D54, D55, D56, D57, D58, D59, D60, D61, D62, D63, D64, D65, D66, D67, D68, D69, D70, D71, D72, D73, D106, D107, D108, D109, D110, D111, D112, D113, D114, D115, D116, D117, D118, D119, D120, D121, D122, D123, D124, D125, D126, D127, D128, D129, D130, D131, D132, D133, D134, D135, D136, D137, D138: SK6812MINI-E; LED_SK6812MINI-E_3.2x2.8mm_P1.5mm_ReverseMount
R1, R3: 806k; R_0805_2012Metric
R2, R4: 1M; R_0805_2012Metric
RV1: R_Potentiometer; Potentiometer_Bourns_PTA2043_Single_Slide
SW1: RotaryEncoder_Switch; RotaryEncoder_Alps_EC11E-Switch_Vertical_H20mm
SW2, SW3, SW4, SW5, SW6, SW7, SW8, SW9, SW10, SW11, SW12, SW13, SW14, SW15, SW16, SW17, SW18, SW19, SW20, SW21, SW22, SW23, SW24, SW25, SW26, SW27, SW28, SW29, SW30, SW31, SW32, SW33, SW38, SW39, SW40, SW41, SW42, SW43, SW44, SW45, SW46, SW47, SW48, SW49, SW50, SW51, SW52, SW53, SW54, SW55, SW56, SW57, SW58, SW59, SW60, SW61, SW62, SW63, SW64, SW65: SW_Push; hotswap_switches
SW34, SW37, SW66, SW67: SW_Push; SW_MX_HS_CPG151101S11_1.75u
SW35, SW69: SW_Push; SW_MX_HS_CPG151101S11_1.25u
SW36, SW68: SW_Push; SW_MX_HS_CPG151101S11_1.5u
TP1, TP3: BAT; TestPoint_Pad_D2.0mm
TP2, TP4: GND; TestPoint_Pad_D2.0mm
U1, U3: MCP23017x-x-SS; SSOP-28_5.3x10.2mm_P0.65mm
U2, U4: XIAO-nRF52840-SMD; modified-XIAO-nRF52840-SMD

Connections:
+3.3V: D37.3 (VDD), D38.3 (VDD), D39.3 (VDD), D40.3 (VDD), D41.3 (VDD), D42.3 (VDD), D43.3 (VDD), D44.3 (VDD), D45.3 (VDD), D46.3 (VDD), D47.3 (VDD), D48.3 (VDD), D49.3 (VDD), D50.3 (VDD), D51.3 (VDD), D52.3 (VDD), D53.3 (VDD), D54.3 (VDD), D55.3 (VDD), D56.3 (VDD), D57.3 (VDD), D58.3 (VDD), D59.3 (VDD), D60.3 (VDD), D61.3 (VDD), D62.3 (VDD), D63.3 (VDD), D64.3 (VDD), D65.3 (VDD), D66.3 (VDD), D67.3 (VDD), D68.3 (VDD), D69.3 (VDD), D70.3 (VDD), D71.3 (VDD), D72.3 (VDD), D73.3 (VDD), D106.3 (VDD), D107.3 (VDD), D108.3 (VDD), D109.3 (VDD), D110.3 (VDD), D111.3 (VDD), D112.3 (VDD), D113.3 (VDD), D114.3 (VDD), D115.3 (VDD), D116.3 (VDD), D117.3 (VDD), D118.3 (VDD), D119.3 (VDD), D120.3 (VDD), D121.3 (VDD), D122.3 (VDD), D123.3 (VDD), D124.3 (VDD), D125.3 (VDD), D126.3 (VDD), D127.3 (VDD), D128.3 (VDD), D129.3 (VDD), D130.3 (VDD), D131.3 (VDD), D132.3 (VDD), D133.3 (VDD), D134.3 (VDD), D135.3 (VDD), D136.3 (VDD), D137.3 (VDD), D138.3 (VDD), RV1.1, U1.9 (V_{DD}), U1.18 (~RESET), U2.12 (3V3), U3.9 (V_{DD}), U3.18 (~RESET), U4.12 (3V3)
/LEFT/BT_PIN: R1.2, R2.1, U2.1 (P0.02_A0_D0)
/LEFT/COL0: SW2.1, SW3.1, SW4.1, SW5.1, SW6.1, SW7.1, U1.21 (GPA0)
/LEFT/COL1: SW8.1, SW9.1, SW10.1, SW11.1, SW12.1, SW13.1, U1.22 (GPA1)
/LEFT/COL2: SW14.1, SW15.1, SW16.1, SW17.1, SW18.1, SW19.1, U1.23 (GPA2)
/LEFT/COL3: SW20.1, SW21.1, SW22.1, SW23.1, SW24.1, SW25.1, U1.24 (GPA3)
/LEFT/COL4: SW26.1, SW27.1, SW28.1, SW29.1, SW30.1, SW31.1, U1.25 (GPA4)
/LEFT/COL5: SW32.1, SW33.1, SW34.1, SW35.1, SW36.1, SW37.1, U1.26 (GPA5)
/LEFT/EA: SW1.A, U1.28 (GPA7)
/LEFT/EB: SW1.B, U1.27 (GPA6)
/LEFT/ES: SW1.S1, U1.1 (GPB0)
/LEFT/ROW0: D1.1 (K), D7.1 (K), D13.1 (K), D19.1 (K), D25.1 (K), D31.1 (K), U2.2 (P0.03_A1_D1)
/LEFT/ROW1: D2.1 (K), D8.1 (K), D14.1 (K), D20.1 (K), D26.1 (K), D32.1 (K), U2.3 (P0.28_A2_D2)
/LEFT/ROW2: D3.1 (K), D9.1 (K), D15.1 (K), D21.1 (K), D27.1 (K), D33.1 (K), U2.4 (P0.29_A3_D3)
/LEFT/ROW3: D4.1 (K), D10.1 (K), D16.1 (K), D22.1 (K), D28.1 (K), D34.1 (K), U2.7 (P1.11_D6_TX)
/LEFT/ROW4: D5.1 (K), D11.1 (K), D17.1 (K), D23.1 (K), D29.1 (K), D35.1 (K), U2.9 (P1.13_D8_SCK)
/LEFT/ROW5: D6.1 (K), D12.1 (K), D18.1 (K), D24.1 (K), D30.1 (K), D36.1 (K), U2.8 (P1.12_D7_RX)
/LEFT/SCL: U1.12 (SCK), U2.6 (P0.05_A5_D5_SCL)
/LEFT/SDA: U1.13 (SDA), U2.5 (P0.04_A4_D4_SDA)
/LEFT/VBAT: R1.1, TP1.1 (1_1)
/RIGHT/BT_PIN: R3.2, R4.1, U4.1 (P0.02_A0_D0)
/RIGHT/COL0: SW38.1, SW39.1, SW40.1, SW41.1, SW42.1, SW43.1, SW44.1, SW45.1, U3.24 (GPA3)
/RIGHT/COL1: SW46.1, SW47.1, SW48.1, SW49.1, SW50.1, SW51.1, SW52.1, SW53.1, U3.25 (GPA4)
/RIGHT/COL2: SW54.1, SW55.1, SW56.1, SW57.1, SW58.1, SW59.1, SW60.1, SW61.1, U3.26 (GPA5)
/RIGHT/COL3: SW62.1, SW63.1, SW64.1, SW65.1, SW66.1, SW67.1, SW68.1, SW69.1, U3.27 (GPA6)
/RIGHT/ROW0: D74.1 (K), D82.1 (K), D90.1 (K), D98.1 (K), U4.3 (P0.28_A2_D2)
/RIGHT/ROW1: D75.1 (K), D83.1 (K), D91.1 (K), D99.1 (K), U4.4 (P0.29_A3_D3)
/RIGHT/ROW2: D76.1 (K), D84.1 (K), D92.1 (K), D100.1 (K), U4.7 (P1.11_D6_TX)
/RIGHT/ROW3: D77.1 (K), D85.1 (K), D93.1 (K), D101.1 (K), U4.8 (P1.12_D7_RX)
/RIGHT/ROW4: D78.1 (K), D86.1 (K), D94.1 (K), D102.1 (K), U4.9 (P1.13_D8_SCK)
/RIGHT/ROW5: D79.1 (K), D87.1 (K), D95.1 (K), D103.1 (K), U3.21 (GPA0)
/RIGHT/ROW6: D80.1 (K), D88.1 (K), D96.1 (K), D104.1 (K), U3.22 (GPA1)
/RIGHT/ROW7: D81.1 (K), D89.1 (K), D97.1 (K), D105.1 (K), U3.23 (GPA2)
/RIGHT/SCL: U3.12 (SCK), U4.6 (P0.05_A5_D5_SCL)
/RIGHT/SDA: U3.13 (SDA), U4.5 (P0.04_A4_D4_SDA)
/RIGHT/Slider: RV1.2, U4.2 (P0.03_A1_D1)
/RIGHT/VBAT: R3.1, TP3.1 (1_1)
GND: D37.1 (VSS), D38.1 (VSS), D39.1 (VSS), D40.1 (VSS), D41.1 (VSS), D42.1 (VSS), D43.1 (VSS), D44.1 (VSS), D45.1 (VSS), D46.1 (VSS), D47.1 (VSS), D48.1 (VSS), D49.1 (VSS), D50.1 (VSS), D51.1 (VSS), D52.1 (VSS), D53.1 (VSS), D54.1 (VSS), D55.1 (VSS), D56.1 (VSS), D57.1 (VSS), D58.1 (VSS), D59.1 (VSS), D60.1 (VSS), D61.1 (VSS), D62.1 (VSS), D63.1 (VSS), D64.1 (VSS), D65.1 (VSS), D66.1 (VSS), D67.1 (VSS), D68.1 (VSS), D69.1 (VSS), D70.1 (VSS), D71.1 (VSS), D72.1 (VSS), D73.1 (VSS), D106.1 (VSS), D107.1 (VSS), D108.1 (VSS), D109.1 (VSS), D110.1 (VSS), D111.1 (VSS), D112.1 (VSS), D113.1 (VSS), D114.1 (VSS), D115.1 (VSS), D116.1 (VSS), D117.1 (VSS), D118.1 (VSS), D119.1 (VSS), D120.1 (VSS), D121.1 (VSS), D122.1 (VSS), D123.1 (VSS), D124.1 (VSS), D125.1 (VSS), D126.1 (VSS), D127.1 (VSS), D128.1 (VSS), D129.1 (VSS), D130.1 (VSS), D131.1 (VSS), D132.1 (VSS), D133.1 (VSS), D134.1 (VSS), D135.1 (VSS), D136.1 (VSS), D137.1 (VSS), D138.1 (VSS), R2.2, R4.2, RV1.3, SW1.C, SW1.S2, TP2.1 (1_1), TP4.1 (1_1), U1.10 (V_{SS}), U1.15 (A0), U1.16 (A1), U1.17 (A2), U2.13 (GND), U3.10 (V_{SS}), U3.15 (A0), U3.16 (A1), U3.17 (A2), U4.13 (GND)
unnamed: D1.2 (A), SW2.2
unnamed: D2.2 (A), SW3.2
unnamed: D3.2 (A), SW4.2
unnamed: D4.2 (A), SW5.2
unnamed: D5.2 (A), SW6.2
unnamed: D6.2 (A), SW7.2
unnamed: D7.2 (A), SW8.2
unnamed: D8.2 (A), SW9.2
unnamed: D9.2 (A), SW10.2
unnamed: D10.2 (A), SW11.2
unnamed: D11.2 (A), SW12.2
unnamed: D12.2 (A), SW13.2
unnamed: D13.2 (A), SW14.2
unnamed: D14.2 (A), SW15.2
unnamed: D15.2 (A), SW16.2
unnamed: D16.2 (A), SW17.2
unnamed: D17.2 (A), SW18.2
unnamed: D18.2 (A), SW19.2
unnamed: D19.2 (A), SW20.2
unnamed: D20.2 (A), SW21.2
unnamed: D21.2 (A), SW22.2
unnamed: D22.2 (A), SW23.2
unnamed: D23.2 (A), SW24.2
unnamed: D24.2 (A), SW25.2
unnamed: D25.2 (A), SW26.2
unnamed: D26.2 (A), SW27.2
unnamed: D27.2 (A), SW28.2
unnamed: D28.2 (A), SW29.2
unnamed: D29.2 (A), SW30.2
unnamed: D30.2 (A), SW31.2
unnamed: D31.2 (A), SW32.2
unnamed: D32.2 (A), SW33.2
unnamed: D33.2 (A), SW34.2
unnamed: D34.2 (A), SW35.2
unnamed: D35.2 (A), SW36.2
unnamed: D36.2 (A), SW37.2
unnamed: D37.4 (DOUT), D38.2 (DIN)
unnamed: D38.4 (DOUT), D39.2 (DIN)
unnamed: D39.4 (DOUT), D40.2 (DIN)
unnamed: D40.4 (DOUT), D41.2 (DIN)
unnamed: D41.4 (DOUT), D42.2 (DIN)
unnamed: D42.4 (DOUT), D48.2 (DIN)
unnamed: D43.2 (DIN), D44.4 (DOUT)
unnamed: D43.4 (DOUT), D49.2 (DIN)
unnamed: D44.2 (DIN), D45.4 (DOUT)
unnamed: D45.2 (DIN), D46.4 (DOUT)
unnamed: D46.2 (DIN), D47.4 (DOUT)
unnamed: D47.2 (DIN), D48.4 (DOUT)
unnamed: D49.4 (DOUT), D50.2 (DIN)
unnamed: D50.4 (DOUT), D51.2 (DIN)
unnamed: D51.4 (DOUT), D52.2 (DIN)
unnamed: D52.4 (DOUT), D53.2 (DIN)
unnamed: D53.4 (DOUT), D54.2 (DIN)
unnamed: D54.4 (DOUT), D60.2 (DIN)
unnamed: D55.2 (DIN), D56.4 (DOUT)
unnamed: D55.4 (DOUT), D61.2 (DIN)
unnamed: D56.2 (DIN), D57.4 (DOUT)
unnamed: D57.2 (DIN), D58.4 (DOUT)
unnamed: D58.2 (DIN), D59.4 (DOUT)
unnamed: D59.2 (DIN), D60.4 (DOUT)
unnamed: D61.4 (DOUT), D62.2 (DIN)
unnamed: D62.4 (DOUT), D63.2 (DIN)
unnamed: D63.4 (DOUT), D64.2 (DIN)
unnamed: D64.4 (DOUT), D65.2 (DIN)
unnamed: D65.4 (DOUT), D66.2 (DIN)
unnamed: D66.4 (DOUT), D72.2 (DIN)
unnamed: D67.2 (DIN), D68.4 (DOUT)
unnamed: D67.4 (DOUT), D73.2 (DIN)
unnamed: D68.2 (DIN), D69.4 (DOUT)
unnamed: D69.2 (DIN), D70.4 (DOUT)
unnamed: D70.2 (DIN), D71.4 (DOUT)
unnamed: D71.2 (DIN), D72.4 (DOUT)
unnamed: D74.2 (A), SW38.2
unnamed: D75.2 (A), SW39.2
unnamed: D76.2 (A), SW40.2
unnamed: D77.2 (A), SW41.2
unnamed: D78.2 (A), SW42.2
unnamed: D79.2 (A), SW43.2
unnamed: D80.2 (A), SW44.2
unnamed: D81.2 (A), SW45.2
unnamed: D82.2 (A), SW46.2
unnamed: D83.2 (A), SW47.2
unnamed: D84.2 (A), SW48.2
unnamed: D85.2 (A), SW49.2
unnamed: D86.2 (A), SW50.2
unnamed: D87.2 (A), SW51.2
unnamed: D88.2 (A), SW52.2
unnamed: D89.2 (A), SW53.2
unnamed: D90.2 (A), SW54.2
unnamed: D91.2 (A), SW55.2
unnamed: D92.2 (A), SW56.2
unnamed: D93.2 (A), SW57.2
unnamed: D94.2 (A), SW58.2
unnamed: D95.2 (A), SW59.2
unnamed: D96.2 (A), SW60.2
unnamed: D97.2 (A), SW61.2
unnamed: D98.2 (A), SW62.2
unnamed: D99.2 (A), SW63.2
unnamed: D100.2 (A), SW64.2
unnamed: D101.2 (A), SW65.2
unnamed: D102.2 (A), SW66.2
unnamed: D103.2 (A), SW67.2
unnamed: D104.2 (A), SW68.2
unnamed: D105.2 (A), SW69.2
unnamed: D106.4 (DOUT), D107.2 (DIN)
unnamed: D107.4 (DOUT), D108.2 (DIN)
unnamed: D108.4 (DOUT), D109.2 (DIN)
unnamed: D109.4 (DOUT), D110.2 (DIN)
unnamed: D110.4 (DOUT), D111.2 (DIN)
unnamed: D111.4 (DOUT), D117.2 (DIN)
unnamed: D112.2 (DIN), D113.4 (DOUT)
unnamed: D112.4 (DOUT), D118.2 (DIN)
unnamed: D113.2 (DIN), D114.4 (DOUT)
unnamed: D114.2 (DIN), D115.4 (DOUT)
unnamed: D115.2 (DIN), D116.4 (DOUT)
unnamed: D116.2 (DIN), D117.4 (DOUT)
unnamed: D118.4 (DOUT), D119.2 (DIN)
unnamed: D119.4 (DOUT), D120.2 (DIN)
unnamed: D120.4 (DOUT), D121.2 (DIN)
unnamed: D121.4 (DOUT), D122.2 (DIN)
unnamed: D122.4 (DOUT), D123.2 (DIN)
unnamed: D123.4 (DOUT), D129.2 (DIN)
unnamed: D124.2 (DIN), D125.4 (DOUT)
unnamed: D124.4 (DOUT), D130.2 (DIN)
unnamed: D125.2 (DIN), D126.4 (DOUT)
unnamed: D126.2 (DIN), D127.4 (DOUT)
unnamed: D127.2 (DIN), D128.4 (DOUT)
unnamed: D128.2 (DIN), D129.4 (DOUT)
unnamed: D130.4 (DOUT), D131.2 (DIN)
unnamed: D131.4 (DOUT), D132.2 (DIN)
unnamed: D132.4 (DOUT), D133.2 (DIN)
unnamed: D133.4 (DOUT), D134.2 (DIN)
unnamed: D134.4 (DOUT), D135.2 (DIN)
unnamed: D135.4 (DOUT), D138.2 (DIN)
unnamed: D136.2 (DIN), D137.4 (DOUT)
unnamed: D137.2 (DIN), D138.4 (DOUT)

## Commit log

2026-08-01 kicad progress incomplete
    [kicad.kicad_pcb, kicad.kicad_sch, left.kicad_sch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]
2026-08-15 routing left side of pcb
    [kicad.kicad_pcb]
2026-08-16 Completed routing left side and started working on right side routing
    [kicad.kicad_pcb]
2026-08-17 right half routing done
    [kicad.kicad_pcb]
2026-08-17 silkscreen art added
    [kicad.kicad_pcb]
2026-08-19 fixed some error with key footprint
    [kicad.dxf, kicad.kicad_pcb, left.csv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]
2026-08-20 pcb images
2026-08-20 fillet corner and photo session
    [kicad.dxf, kicad.kicad_pcb]
2026-08-21 started cad
    [kicad.dxf, kicad.kicad_pcb]
2026-08-28 forgot to commit yesterday
    [EC11_Rotary_Encoder_Switched.step, HS_CPG151101S11_MX.step, XIAO-nRF52840 v15.step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]
2026-08-28 bom didnt format properly
    [BOM.csv]
2026-08-28 BOM againg
    [BOM (1).csv]
2026-08-28 bom yet again
    [BOM.csv]
2026-08-28 old bom delete
    [BOM (1).csv]
2026-08-29 3d print files and gerbers
    [kicad-B_Adhesive.gbr, kicad-B_Courtyard.gbr, kicad-B_Cu.gbr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]
2026-08-29 completed bom and reorganize production files
    [BOM.csv, left bottom case.step, left bottom case.stl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]
2026-08-29 added product links back
    [BOM.csv]
2026-08-29 fixed some broken links
    [BOM.csv]
2026-08-29 Update README with total cost in BOM section
    Added total cost information to the Bill of Materials section.
2026-09-03 cheaper options found thx to neeraj on slack
    [BOM.csv]
2026-09-03 summary bom added
2026-09-03 updates stuff for 20mm screws also added better logo
    [1.25u keycap black.step, 1.25u keycaps black.stl, 1.25u keycaps grey.step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]
2026-09-03 added keycap in 3d prints
